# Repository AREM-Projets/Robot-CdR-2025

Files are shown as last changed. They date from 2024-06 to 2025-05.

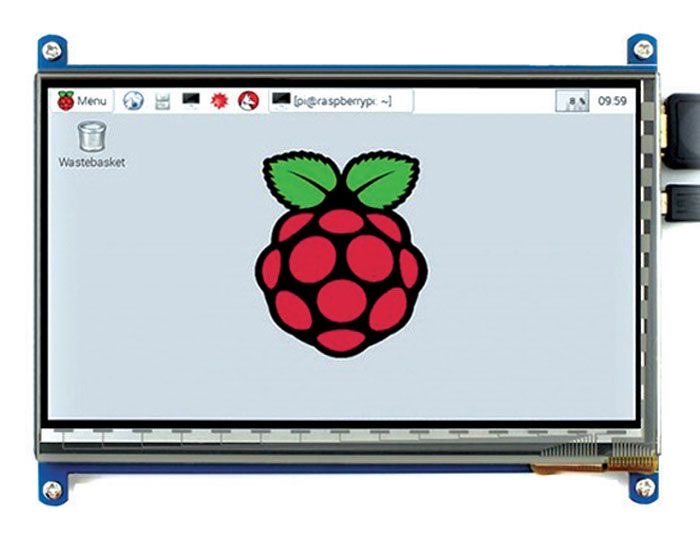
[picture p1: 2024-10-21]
Docs/Architecture ancienne du robot/Images/ecran_tactile.jpg

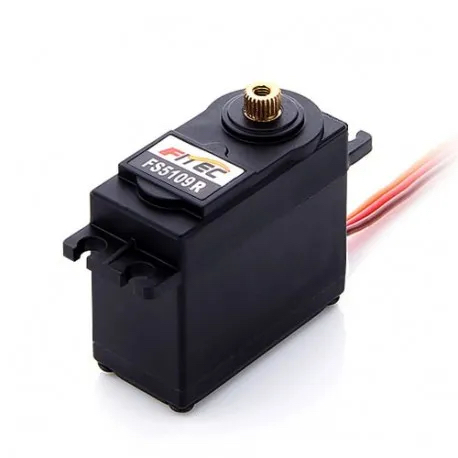
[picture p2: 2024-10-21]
Docs/Architecture ancienne du robot/Images/servo.webp

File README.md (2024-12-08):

# Robot-CdR-2025

Repo contenant l'ensemble des documents liés au robot de la coupe de France de Robotique 2025

## Liens utiles

* [Notion des tâches à réaliser](https://gevorgs.notion.site/2f7c12f6feff4595ba645344655ddd17?v=308f1cf20fb54248941d14f6b965dd2d)
* [Lien vers le règlement](https://www.coupederobotique.fr/accueil/le-concours/reglement-2025/)

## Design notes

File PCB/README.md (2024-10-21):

# PCB utilisés pour le robot de la CdR 2025

* PCB Alimentation
* PCB Shield STM32 Embase

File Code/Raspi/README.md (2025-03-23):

# Robot-CdR-2025

Repo contenant l'ensemble du code du robot de la coupe de France de Robotique 2025.

## TODO

- Faire un script bash qui démarre le main.py du robot, crées la fifo_lidar_to_raspi et démarre le driver_lidar

## LIDAR

>**Compilation du driver lidar**: ``bash driver_lidar_compilation.sh``
>**Démarrage du driver lidar**: ``./driver_lidar --channel --serial /dev/ttyUSB0 460800``

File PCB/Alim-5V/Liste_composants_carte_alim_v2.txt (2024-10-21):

ok	4 connecteurs jack femelle
ok	1 led rouge
ok	1 resistance 1kOhms
ok	1 fusible
ok	8 JST 2 pin femelles
nok	1 Port XT60 femelle (on a les mâles)
ok	3 Bucks

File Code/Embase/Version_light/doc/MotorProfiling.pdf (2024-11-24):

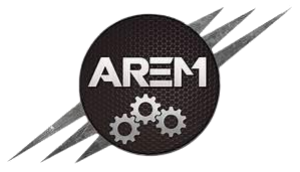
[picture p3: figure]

# [Component Test] Stepper Motor

Date : 08/01/22

Author : Adrien Komaroff-Kourloff

Purpose of the task:

- Principle: Operate the stepper motor that will be used on both robots. Write a brief report on its operation (including the written functions). Find the optimal operating parameters for the motor.
- Objectives: Familiarize yourself with the operation of stepper motors, prepare for their integration into the code.

## Ressources :

To understand the principle of a stepper motor: Stepper Motor Principle (http://ressources.univ-lemans.fr/AccesLibre/UM/Pedago/physique/02/electri/pasapas.html)

For information on micro-stepping: Microstepping Basics (https://www.linearmotiontips.com/microstepping-basics/)

The hardware connections to be made are detailed in the motor shield component test.

## Parameter Optimization

To achieve the best performance with the motors, it is necessary to have a good understanding of the parameters in the BlocMoteurs.h file :

Modify that struct : init for each motor

De L6470_init_t initShield[L6470DAISYCHAINSIZE]

For this purpose, I have adapted the content of this technical document, which is recommended reading: STMicroelectronics Voltage Mode Control Operation and Parameter Optimization. (https://www.st.com/resource/en/application_note/an4144-voltage-mode-control-operation-and-parameter-optimization-stmicroelectronics.pdf)

Please be aware that the library already performs some calculations after filling in L6470_init_t, and the units and quantities in this technical note may not be exactly the same as what needs to be filled in. You should adapt them based on a study of this library and its various functions.

To find the motor parameters, you need to have various parameters available in the motor datasheet and obtain them through measurement.

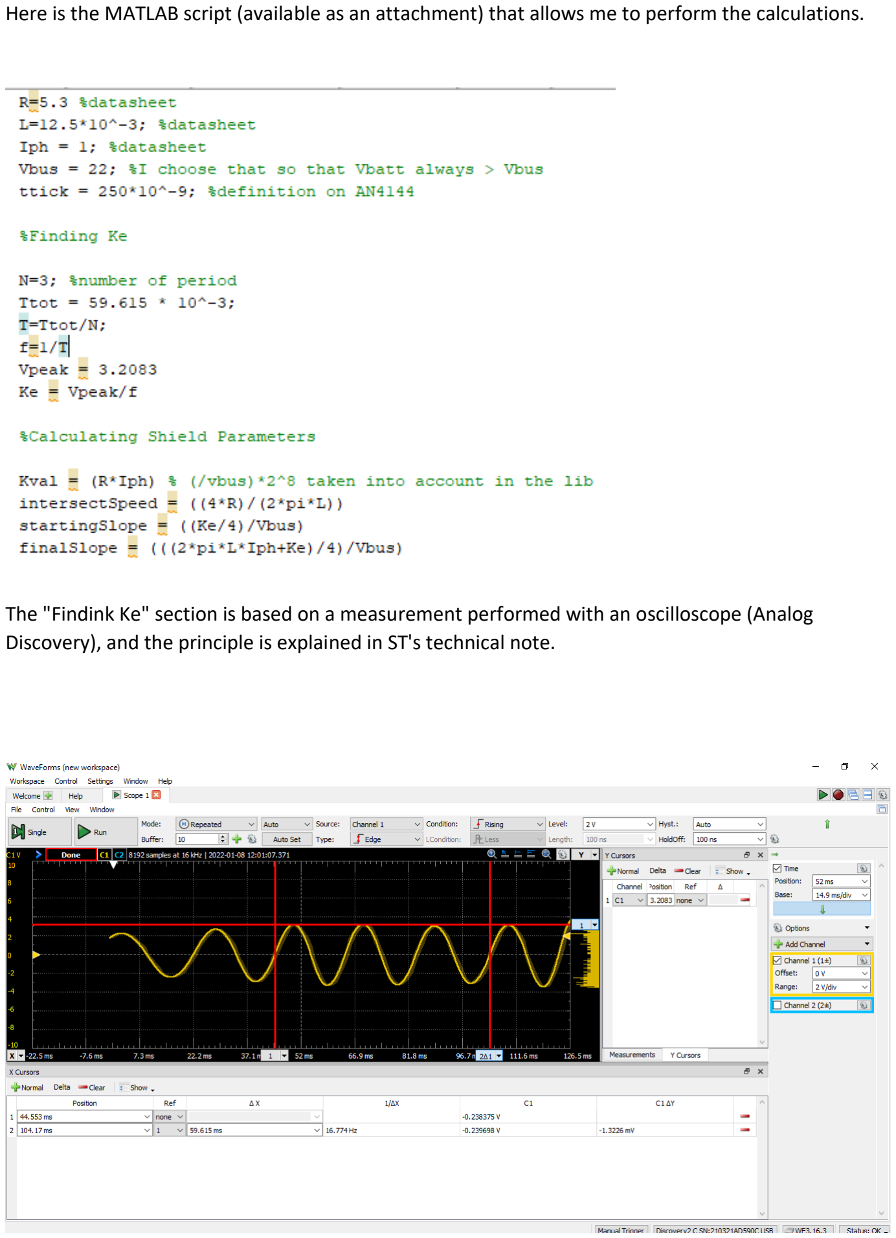
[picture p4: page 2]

Here is the MATLAB script (available as an attachment) that allows me to perform the calculations.

The "Findink Ke" section is based on a measurement performed with an oscilloscope (Analog Discovery), and the principle is explained in ST's technical note.

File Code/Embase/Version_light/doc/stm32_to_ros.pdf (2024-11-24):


01/11/2023

stm32_to_ros Project
Configuration Report

## 1. Description

### 1.1. Project

Project Name | stm32_to_ros
Board Name | NUCLEO-F446RE
Generated with: | STM32CubeMX 6.9.2
Date | 11/01/2023

### 1.2. MCU

MCU Series | STM32F4
MCU Line | STM32F446
MCU name | STM32F446RETx
MCU Package | LQFP64
MCU Pin number | 64

### 1.3. Core(s) information

Core(s) | Arm Cortex-M4

## 2. Pinout Configuration

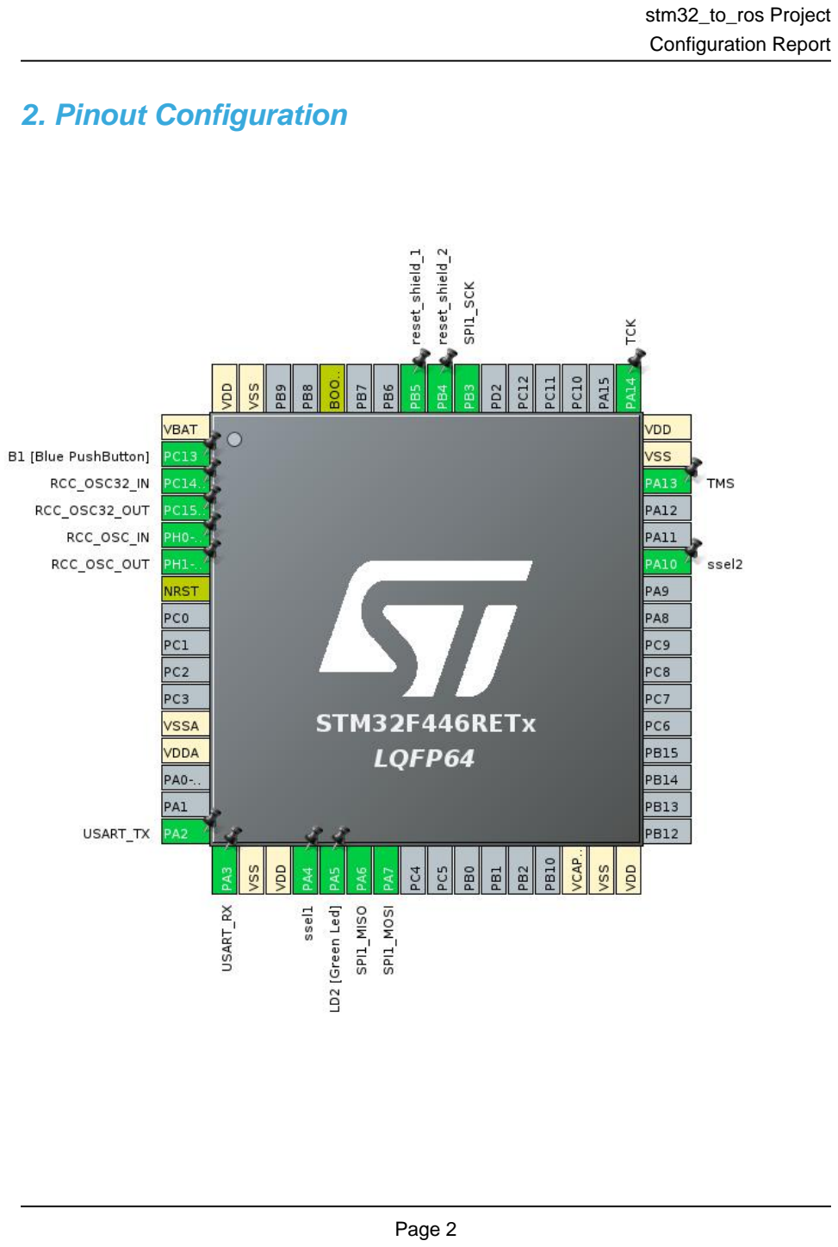
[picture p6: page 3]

## 3. Pins Configuration

Pin Number LQFP64 | Pin Name (function after reset) | Pin Type | Alternate Function(s) | Label
1 | VBAT | Power
2 | PC13 | I/O | GPIO_EXTI13 | B1 [Blue PushButton]
3 | PC14-OSC32_IN | I/O | RCC_OSC32_IN
4 | PC15-OSC32_OUT | I/O | RCC_OSC32_OUT
5 | PH0-OSC_IN | I/O | RCC_OSC_IN
6 | PH1-OSC_OUT | I/O | RCC_OSC_OUT
7 | NRST | Reset
12 | VSSA | Power
13 | VDDA | Power
16 | PA2 | I/O | USART2_TX | USART_TX
17 | PA3 | I/O | USART2_RX | USART_RX
18 | VSS | Power
19 | VDD | Power
20 | PA4 * | I/O | GPIO_Output | ssel1
21 | PA5 * | I/O | GPIO_Output | LD2 [Green Led]
22 | PA6 | I/O | SPI1_MISO
23 | PA7 | I/O | SPI1_MOSI
30 | VCAP_1 | Power
31 | VSS | Power
32 | VDD | Power
43 | PA10 * | I/O | GPIO_Output | ssel2
46 | PA13 | I/O | SYS_JTMS-SWDIO | TMS
47 | VSS | Power
48 | VDD | Power
49 | PA14 | I/O | SYS_JTCK-SWCLK | TCK
55 | PB3 | I/O | SPI1_SCK
56 | PB4 * | I/O | GPIO_Output | reset_shield_2
57 | PB5 * | I/O | GPIO_Output | reset_shield_1
60 | BOOT0 | Boot
63 | VSS | Power
64 | VDD | Power

* The pin is affected with an I/O function

## 4. Clock Tree Configuration

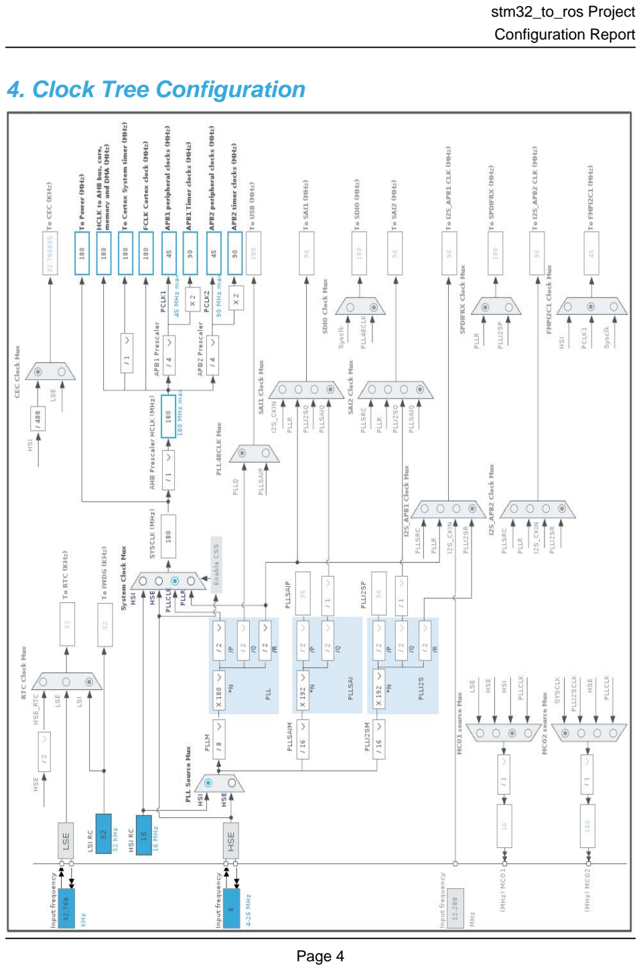
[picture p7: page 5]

## 5. Software Project

### 5.1. Project Settings

Name | Value
Project Name | stm32_to_ros
Project Folder | /home/adrien/STM32CubeIDE/workspace_1.13.2/stm32_to_ros
Toolchain / IDE | STM32CubeIDE
Firmware Package Name and Version | STM32Cube FW_F4 V1.27.1
Application Structure | Advanced
Generate Under Root | Yes
Do not generate the main() | No
Minimum Heap Size | 0x200
Minimum Stack Size | 0x400

### 5.2. Code Generation Settings

Name | Value
STM32Cube MCU packages and embedded software | Copy only the necessary library files
Generate peripheral initialization as a pair of '.c/.h' files | No
Backup previously generated files when re-generating | No
Keep User Code when re-generating | Yes
Delete previously generated files when not re-generated | Yes
Set all free pins as analog (to optimize the power consumption) | No
Enable Full Assert | No

### 5.3. Advanced Settings - Generated Function Calls

Rank | Function Name | Peripheral Instance Name
1 | SystemClock_Config | RCC
2 | MX_GPIO_Init | GPIO
3 | MX_USART2_UART_Init | USART2
4 | MX_TIM2_Init | TIM2
5 | MX_SPI1_Init | SPI1

## 1. Power Consumption Calculator report

### 1.1. Microcontroller Selection

Series | STM32F4
Line | STM32F446
MCU | STM32F446RETx
Datasheet | DS10693_Rev6

### 1.2. Parameter Selection

Temperature | 25
Vdd | 3.3

### 1.3. Battery Selection

Battery | Li-SOCL2(A3400)
Capacity | 3400.0 mAh
Self Discharge | 0.08 %/month
Nominal Voltage | 3.6 V
Max Cont Current | 100.0 mA
Max Pulse Current | 200.0 mA
Cells in series | 1
Cells in parallel | 1

### 1.4. Sequence

Step | Step1 | Step2
Mode | RUN | STOP_UDM (Under Drive)
Vdd | 3.3 | 3.3
Voltage Source | Battery | Battery
Range | Scale1-High | No Scale
Fetch Type | RAM/FLASH/REGON/ART/P REFETCH | n/a
CPU Frequency | 180 MHz | 0 Hz
Clock Configuration | HSE PLL | Regulator_LP Flash-PwrDwn
Clock Source Frequency | 4 MHz | 0 Hz
Peripherals
Additional Cons. | 0 mA | 0 mA
Average Current | 46 mA | 55 µA
Duration | 0.1 ms | 0.9 ms
DMIPS | 225.0 | 0.0
Ta Max | 98.02 | 104.99
Category | In DS Table | In DS Table

### 1.5. Results

Sequence Time | 1 ms | Average Current | 4.65 mA
Battery Life | 1 month | Average DMIPS | 225.0 DMIPS

### 1.6. Chart

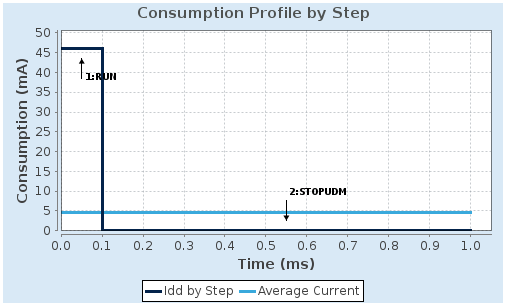
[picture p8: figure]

## 2. Peripherals and Middlewares Configuration

### 2.1. RCC

High Speed Clock (HSE): Crystal/Ceramic Resonator
Low Speed Clock (LSE) : Crystal/Ceramic Resonator
2.1.1. Parameter Settings:

System Parameters:

VDD voltage (V) | 3.3
Instruction Cache | Enabled
Prefetch Buffer | Enabled
Data Cache | Enabled
Flash Latency(WS) | 5 WS (6 CPU cycle)
RCC Parameters:
HSI Calibration Value | 16
TIM Prescaler Selection | Disabled
HSE Startup Timout Value (ms) | 100
LSE Startup Timout Value (ms) | 5000
Power Parameters:
Power Regulator Voltage Scale | Power Regulator Voltage Scale 1
Power Over Drive | Enabled

### 2.2. SPI1

Mode: Full-Duplex Master
2.2.1. Parameter Settings:

Basic Parameters:

Frame Format | Motorola
Data Size | 8 Bits
First Bit | MSB First
Clock Parameters:
Prescaler (for Baud Rate) | 8 *
Baud Rate | 5.625 MBits/s *
Clock Polarity (CPOL) | High *
Clock Phase (CPHA) | 2 Edge *
Advanced Parameters:
CRC Calculation | Disabled
NSS Signal Type | Software

### 2.3. SYS

Debug: Serial Wire
Timebase Source: SysTick

### 2.4. TIM2

Clock Source : Internal Clock
2.4.1. Parameter Settings:

Counter Settings:

Prescaler (PSC - 16 bits value) | 0
Counter Mode | Up
Counter Period (AutoReload Register - 32 bits value ) | 1800000 *
Internal Clock Division (CKD) | No Division
auto-reload preload | Enable *
Trigger Output (TRGO) Parameters:
Master/Slave Mode (MSM bit) | Disable (Trigger input effect not delayed)
Trigger Event Selection | Reset (UG bit from TIMx_EGR)

### 2.5. USART2

Mode: Asynchronous
2.5.1. Parameter Settings:

Basic Parameters:

Baud Rate | 115200
Word Length | 8 Bits (including Parity)
Parity | None
Stop Bits | 1
Advanced Parameters:
Data Direction | Receive and Transmit
Over Sampling | 16 Samples

* User modified value

## 3. System Configuration

### 3.1. GPIO configuration

IP | Pin | Signal | GPIO mode | GPIO pull/up pull down | Max Speed | User Label
RCC | PC14-OSC32_IN | RCC_OSC32_IN | n/a | n/a | n/a
| PC15-OSC32_OU T | RCC_OSC32_O UT | n/a | n/a | n/a
| PH0-OSC_IN | RCC_OSC_IN | n/a | n/a | n/a
| PH1-OSC_OUT | RCC_OSC_OUT | n/a | n/a | n/a
SPI1 | PA6 | SPI1_MISO | Alternate Function Push Pull | No pull-up and no pull-down | Very High *
| PA7 | SPI1_MOSI | Alternate Function Push Pull | No pull-up and no pull-down | Very High *
| PB3 | SPI1_SCK | Alternate Function Push Pull | No pull-up and no pull-down | Very High *
SYS | PA13 | SYS_JTMS-SWDIO | n/a | n/a | n/a | TMS
| PA14 | SYS_JTCK-SWCLK | n/a | n/a | n/a | TCK
USART2 | PA2 | USART2_TX | Alternate Function Push Pull | No pull-up and no pull-down | Very High * | USART_TX
| PA3 | USART2_RX | Alternate Function Push Pull | No pull-up and no pull-down | Very High * | USART_RX
GPIO | PC13 | GPIO_EXTI13 | External Interrupt Mode with Falling edge trigger detection | No pull-up and no pull-down | n/a | B1 [Blue PushButton]
| PA4 | GPIO_Output | Output Push Pull | No pull-up and no pull-down | Low | ssel1
| PA5 | GPIO_Output | Output Push Pull | No pull-up and no pull-down | Low | LD2 [Green Led]
| PA10 | GPIO_Output | Output Push Pull | No pull-up and no pull-down | Low | ssel2
| PB4 | GPIO_Output | Output Push Pull | No pull-up and no pull-down | Low | reset_shield_2
| PB5 | GPIO_Output | Output Push Pull | No pull-up and no pull-down | Low | reset_shield_1

### 3.2. DMA configuration

nothing configured in DMA service

### 3.3. NVIC configuration

3.3.1. NVIC
Interrupt Table | Enable | Preenmption Priority | SubPriority
Non maskable interrupt | true | 0 | 0
Hard fault interrupt | true | 0 | 0
Memory management fault | true | 0 | 0
Pre-fetch fault, memory access fault | true | 0 | 0
Undefined instruction or illegal state | true | 0 | 0
System service call via SWI instruction | true | 0 | 0
Debug monitor | true | 0 | 0
Pendable request for system service | true | 0 | 0
System tick timer | true | 0 | 0
TIM2 global interrupt | true | 0 | 2
USART2 global interrupt | true | 0 | 0
PVD interrupt through EXTI line 16 | unused
Flash global interrupt | unused
RCC global interrupt | unused
SPI1 global interrupt | unused
EXTI line[15:10] interrupts | unused
FPU global interrupt | unused
3.3.2. NVIC Code generation
Enabled interrupt Table | Select for init sequence ordering | Generate IRQ handler | Call HAL handler
Non maskable interrupt | false | true | false
Hard fault interrupt | false | true | false
Memory management fault | false | true | false
Pre-fetch fault, memory access fault | false | true | false
Undefined instruction or illegal state | false | true | false
System service call via SWI instruction | false | true | false
Debug monitor | false | true | false
Pendable request for system service | false | true | false
System tick timer | false | true | true
TIM2 global interrupt | false | true | true
USART2 global interrupt | false | true | true

* User modified value

## 4. System Views

4.1. Category view
4.1.1. Current

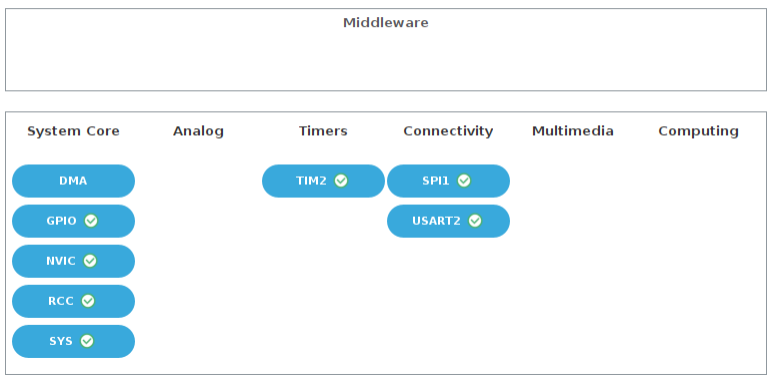
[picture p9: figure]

## 5. Docs & Resources

Type | Link
BSDL files | https://www.st.com/resource/en/bsdl_model/stm32f446_bsdl.zip
IBIS models | https://www.st.com/resource/en/ibis_model/stm32f446_ibis.zip
System View Description | https://www.st.com/resource/en/svd/stm32f4_svd.zip
Presentations | https://www.st.com/resource/en/product_presentation/stm32-stm8_embedded_software_solutions.pdf
Presentations | https://www.st.com/resource/en/product_presentation/stm32_eval-tools_portfolio.pdf
Presentations | https://www.st.com/resource/en/product_presentation/stm32_stm8_functi onal-safety-packages.pdf
Presentations | https://www.st.com/resource/en/product_presentation/stm32-stm8_software_development_tools.pdf
Brochures | https://www.st.com/resource/en/brochure/products-and-solutions-for-plcs-and-smart-i-os.pdf
Flyers | https://www.st.com/resource/en/flyer/flstm32nucleo.pdf
Flyers | https://www.st.com/resource/en/flyer/flstmcsuite.pdf
Flyers | https://www.st.com/resource/en/flyer/flstm32trust.pdf
Product Certifications | https://www.st.com/resource/en/certification_document/stm32_authentication_can.pdf
Application Notes | https://www.st.com/resource/en/application_note/an1181-electrostatic-discharge-sensitivity-measurement-stmicroelectronics.pdf
Application Notes | https://www.st.com/resource/en/application_note/an1709-emc-design-guide-for-stm8-stm32-and-legacy-mcus-stmicroelectronics.pdf
Application Notes | https://www.st.com/resource/en/application_note/an2606-stm32-microcontroller-system-memory-boot-mode-stmicroelectronics.pdf
Application Notes | https://www.st.com/resource/en/application_note/an2639-soldering-recommendations-and-package-information-for-leadfree-ecopack-mcus-and-mpus-stmicroelectronics.pdf
Application Notes | https://www.st.com/resource/en/application_note/an2834-how-to-get-the-

| best-adc-accuracy-in-stm32-microcontrollers-stmicroelectronics.pdf
Application Notes | https://www.st.com/resource/en/application_note/an2867-oscillator-design-guide-for-stm8afals-stm32-mcus-and-mpus-stmicroelectronics.pdf
Application Notes | https://www.st.com/resource/en/application_note/an2945-stm8s-and-stm32-mcus-a-consistent-832bit-product-line-for-painless-migration-stmicroelectronics.pdf
Application Notes | https://www.st.com/resource/en/application_note/an3070-managing-the-driver-enable-signal-for-rs485-and-iolink-communications-with-the-stm32s-usart-stmicroelectronics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
Application Notes | https://www.st.com/resource/en/application_note/an3126-audio-and-waveform-generation-using-the-dac-in-stm32-products-stmicroelectronics.pdf
Application Notes | https://www.st.com/resource/en/application_note/an3154-can-protocol-used-in-the-stm32-bootloader-stmicroelectronics.pdf
Application Notes | https://www.st.com/resource/en/application_note/an3155-usart-protocol-used-in-the-stm32-bootloader-stmicroelectronics.pdf
Application Notes | https://www.st.com/resource/en/application_note/an3156-usb-dfu-protocol-used-in-the-stm32-bootloader-stmicroelectronics.pdf
Application Notes | https://www.st.com/resource/en/application_note/an3364-migration-and-compatibility-guidelines-for-stm32-microcontroller-applications-stmicroelectronics.pdf
Application Notes | https://www.st.com/resource/en/application_note/an3997-audio-playback-and-recording-using-the-stm32f4discovery-stmicroelectronics.pdf
Application Notes | https://www.st.com/resource/en/application_note/an3998-pdm-audio-software-decoding-on-stm32-microcontrollers-stmicroelectronics.pdf
Application Notes | https://www.st.com/resource/en/application_note/an4013-stm32-crossseries-timer-overview-stmicroelectronics.pdf
Application Notes | https://www.st.com/resource/en/application_note/an4031-using-the-stm32f2-stm32f4-and-stm32f7-series-dma-controller-stmicroelectronics.pdf
Application Notes | https://www.st.com/resource/en/application_note/an4221-i2c-protocol-used-in-the-stm32-bootloader-stmicroelectronics.pdf
Application Notes | https://www.st.com/resource/en/application_note/an4229-how-to-

| implement-a-vocoder-solution-using-stm32-microcontrollers-stmicroelectronics.pdf
Application Notes | https://www.st.com/resource/en/application_note/an4277-using-stm32-device-pwm-shutdown-features-for-motor-control-and-digital-power-conversion-stmicroelectronics.pdf
Application Notes | https://www.st.com/resource/en/application_note/an4286-spi-protocol-used-in-the-stm32-bootloader-stmicroelectronics.pdf
Application Notes | https://www.st.com/resource/en/application_note/an4488-getting-started-with-stm32f4xxxx-mcu-hardware-development-stmicroelectronics.pdf
Application Notes | https://www.st.com/resource/en/application_note/an4566-extending-the-dac-performance-of-stm32-microcontrollers-stmicroelectronics.pdf
Application Notes | https://www.st.com/resource/en/application_note/an4640-peripherals-interconnections-on-stm32f4057xx-stm32f4157xx-stm32f42xxx-stm32f43xxx-stm32f446xx-and-stm32f469479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
Application Notes | https://www.st.com/resource/en/application_note/an4655-virtually-increasing-the-number-of-serial-communication-peripherals-in-stm32-applications-stmicroelectronics.p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
Application Notes | https://www.st.com/resource/en/application_note/an4658-migration-of-applications-from-stm32f429439-lines-to-stm32f446-line-stmicroelectronics.pdf
Application Notes | https://www.st.com/resource/en/application_note/an4739-stm32cube-firmware-examples-for-stm32f4-series-stmicroelectronics.pdf
Application Notes | https://www.st.com/resource/en/application_note/an4750-handling-of-soft-errors-in-stm32-applications-stmicroelectronics.pdf
Application Notes | https://www.st.com/resource/en/application_note/an4759-using-the-hardware-realtime-clock-rtc-and-the-tamper-management-unit-tamp-with-stm32-microcontrollers-stmicroe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
Application Notes | https://www.st.com/resource/en/application_note/an4776-generalpurpose-timer-cookbook-for-stm32-microcontrollers-stmicroelectronics.pdf
Application Notes | https://www.st.com/resource/en/application_note/an4803-highspeed-si-simulations-using-ibis-and-boardlevel-simulations-using-hyperlynx-si-on-stm32-mcus-and-mpus-stmic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
Application Notes | https://www.st.com/resource/en/application_note/an4850-stm32-mcus-

| spreadspectrum-clock-generation-principles-properties-and-implementation-stmicroelectronics.pdf
Application Notes | https://www.st.com/resource/en/application_note/an4908-stm32-usart-automatic-baud-rate-detection-stmicroelectronics.pdf
Application Notes | https://www.st.com/resource/en/application_note/an4989-stm32-microcontroller-debug-toolbox-stmicroelectronics.pdf
Application Notes | https://www.st.com/resource/en/application_note/an4995-using-an-electromyogram-technique-to-detect-muscle-activity-stmicroelectronics.pdf
Application Notes | https://www.st.com/resource/en/application_note/an5020-digital-camera-interface-dcmi-on-stm32-mcus-stmicroelectronics.pdf
Application Notes | https://www.st.com/resource/en/application_note/an5027-interfacing-pdm-digital-microphones-using-stm32-mcus-and-mpus-stmicroelectronics.pdf
Application Notes | https://www.st.com/resource/en/application_note/an5036-thermal-management-guidelines-for-stm32-applications-stmicroelectronics.pdf
Application Notes | https://www.st.com/resource/en/application_note/an5073-receiving-spdif-audio-stream-with-the-stm32f4f7h7-series-stmicroelectronics.pdf
Application Notes | https://www.st.com/resource/en/application_note/an5225-usb-typec-power-delivery-using-stm32-mcus-and-mpus-stmicroelectronics.pdf
Application Notes | https://www.st.com/resource/en/application_note/an5543-enhanced-methods-to-handle-spi-communication-on-stm32-devices-stmicroelectronics.pdf
Application Notes | https://www.st.com/resource/en/application_note/an4760-quadspi-interface-on-stm32-microcontrollers-and-microprocessors--stmicroelectronics.pdf
Application Notes | https://www.st.com/resource/en/application_note/an4899-stm32-microcontroller-gpio-hardware-settings-and-lowpower-consumption-stmicroelectronics.pdf
Application Notes | https://www.st.com/resource/en/application_note/an5612-esd-protection-of-stm32-mcus-and-mpus-stmicroelectronics.pdf
Application Notes | https://www.st.com/resource/en/application_note/an5156-introduction-to-stm32-microcontrollers-security-stmicroelectronics.pdf
Application Notes | https://www.st.com/resource/en/application_note/an4838-introduction-to-

| memory-protection-unit-management-on-stm32-mcus-stmicroelectronics.pdf
Application Notes | https://www.st.com/resource/en/application_note/an4230-random-number-generation-validation-using-nist-statistical-test-suite-for-stm32-microcontrollers-stmicroelectr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
Application Notes | https://www.st.com/resource/en/application_note/an4879-introduction-to-usb-hardware-and-pcb-guidelines-using-stm32-mcus-stmicroelectronics.pdf
Application Notes for related Tools & Software | https://www.st.com/resource/en/application_note/an1202_freertos_guide-freertos-guide-stmicroelectronics.pdf
Application Notes for related Tools & Software | https://www.st.com/resource/en/application_note/an1602_semihosting_in_truestudio-how-to-do-semihosting-in-truestudio-stmicroelectronics.pdf
Application Notes for related Tools & Software | https://www.st.com/resource/en/application_note/an1801_stm32cubeprogrammer_in_truestudio-installing-stm32cubeprogrammer-in-truestudio-stmicroelectronics.pdf
Application Notes for related Tools & Software | https://www.st.com/resource/en/application_note/atollic_editing_keyboard_shortcuts-atollic-editing-keyboard-shortcuts-stmicroelectronics.pdf
Application Notes for related Tools & Software | https://www.st.com/resource/en/application_note/iar_to_atollic_truestudio_migration_guide-truestudio-for-arm-migration-guide-iar-embedded-workbench-to-truestudio-stm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
Application Notes for related Tools & Software | https://www.st.com/resource/en/application_note/stm32cubemx_installation_in_truestudio-stm32cubemx-installation-in-truestudio-stmicroelectronics.pdf
Application Notes for related Tools & Software | https://www.st.com/resource/en/application_note/an2656-stm32f10xxx-lcd-glass-driver-firmware-stmicroelectronics.pdf
Application Notes for related Tools & Software | https://www.st.com/resource/en/application_note/an2790-tft-lcd-interfacing-with-the-highdensity-stm32f10xxx-fsmc-stmicroelectronics.pdf

Application Notes
for related Tools

https://www.st.com/resource/en/application_note/an3078-stm32-inapplication-programming-over-the-ic-bus-stmicroelectronics.pdf

& Software
Application Notes for related Tools & Software | https://www.st.com/resource/en/application_note/an3116-stm32s-adc-modes-and-their-applications-stmicroelectronics.pdf
Application Notes for related Tools & Software | https://www.st.com/resource/en/application_note/an3174-implementing-receivers-for-infrared-remote-control-protocols-using-stm32f10xxx-microcontrollers-stmicroelectro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
Application Notes for related Tools & Software | https://www.st.com/resource/en/application_note/an3241-qvga-tftlcd-direct-drive-using-the-stm32f10xx-fsmc-peripheral-stmicroelectronics.pdf
Application Notes for related Tools & Software | https://www.st.com/resource/en/application_note/an3307-guidelines-for-obtaining-iec-60335-class-b-certification-for-any-stm32-application-stmicroelectronics.pdf
Application Notes for related Tools & Software | https://www.st.com/resource/en/application_note/an3364-migration-and-compatibility-guidelines-for-stm32-microcontroller-applications-stmicroelectronics.pdf
Application Notes for related Tools & Software | https://www.st.com/resource/en/application_note/an3965-stm32f40xstm32f41x-inapplication-programming-using-the-usart-stmicroelectronics.pdf
Application Notes for related Tools & Software | https://www.st.com/resource/en/application_note/an3969-eeprom-emulation-in-stm32f40xstm32f41x-microcontrollers-stmicroelectronics.pdf
Application Notes for related Tools & Software | https://www.st.com/resource/en/application_note/an3990-upgrading-stm32f4discovery-board-firmware-using-a-usb-key-stmicroelectronics.pdf
Application Notes for related Tools & Software | https://www.st.com/resource/en/application_note/an3997-audio-playback-and-recording-using-the-stm32f4discovery-stmicroelectronics.pdf
Application Notes for related Tools & Software | https://www.st.com/resource/en/application_note/an3998-pdm-audio-software-decoding-on-stm32-microcontrollers-stmicroelectronics.pdf
Application Notes for related Tools & Software | https://www.st.com/resource/en/application_note/an4044-floating-point-unit-demonstration-on-stm32-microcontrollers-stmicroelectronics.pdf

Application Notes for related Tools & Software | https://www.st.com/resource/en/application_note/an4323-getting-started-with-stemwin-library-stmicroelectronics.pdf
Application Notes for related Tools & Software | https://www.st.com/resource/en/application_note/an4365-using-stm32f4-mcu-power-modes-with-best-dynamic-efficiency-stmicroelectronics.pdf
Application Notes for related Tools & Software | https://www.st.com/resource/en/application_note/an4435-guidelines-for-obtaining-ulcsaiec-607301603351-class-b-certification-in-any-stm32-application-stmicroelectroni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
Application Notes for related Tools & Software | https://www.st.com/resource/en/application_note/an4457-implementing-an-emulated-uart-on-stm32f4-microcontrollers-stmicroelectronics.pdf
Application Notes for related Tools & Software | https://www.st.com/resource/en/application_note/an4499-stm32--nrf51822-bluetooth-low-energy-system-solution-stmicroelectronics.pdf
Application Notes for related Tools & Software | https://www.st.com/resource/en/application_note/an4657-stm32-inapplication-programming-iap-using-the-usart-stmicroelectronics.pdf
Application Notes for related Tools & Software | https://www.st.com/resource/en/application_note/an4666-parallel-synchronous-transmission-using-gpio-and-dma-stmicroelectronics.pdf
Application Notes for related Tools & Software | https://www.st.com/resource/en/application_note/an4678-full-duplex-spi-emulation-for-stm32f4-microcontrollers-stmicroelectronics.pdf
Application Notes for related Tools & Software | https://www.st.com/resource/en/application_note/an4701-proprietary-code-readout-protection-on-microcontrollers-of-the-stm32f4-series-stmicroelectronics.pdf
Application Notes for related Tools & Software | https://www.st.com/resource/en/application_note/an4739-stm32cube-firmware-examples-for-stm32f4-series-stmicroelectronics.pdf
Application Notes for related Tools & Software | https://www.st.com/resource/en/application_note/an4758-proprietary-code-readout-protection-on-stm32l4-stm32l4-stm32g4-and-stm32wb-series-mcus-stmicroelectronics.pdf
Application Notes | https://www.st.com/resource/en/application_note/an4759-using-the-

for related Tools & Software | hardware-realtime-clock-rtc-and-the-tamper-management-unit-tamp-with-stm32-microcontrollers-stmicroelectronics.pdf
Application Notes for related Tools & Software | https://www.st.com/resource/en/application_note/an4841-digital-signal-processing-for-stm32-microcontrollers-using-cmsis-stmicroelectronics.pdf
Application Notes for related Tools & Software | https://www.st.com/resource/en/application_note/an4852-programming-an-external-flash-memory-using-the-uart-bootloader-builtin-stm32-microcontrollers-stmicroelectroni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
Application Notes for related Tools & Software | https://www.st.com/resource/en/application_note/an4968-proprietary-code-read-out-protection-pcrop-on-stm32f72xxx-and-stm32f73xxx-microcontrollers-stmicroelectronics.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
Application Notes for related Tools & Software | https://www.st.com/resource/en/application_note/an5054-secure-programming-using-stm32cubeprogrammer-stmicroelectronics.pdf
Application Notes for related Tools & Software | https://www.st.com/resource/en/application_note/an5056-integration-guide-for-the-xcubesbsfu-stm32cube-expansion-package-stmicroelectronics.pdf
Application Notes for related Tools & Software | https://www.st.com/resource/en/application_note/an5360-getting-started-with-projects-based-on-the-stm32mp1-series-in-stm32cubeide-stmicroelectronics.pdf
Application Notes for related Tools & Software | https://www.st.com/resource/en/application_note/an5361-getting-started-with-projects-based-on-dualcore-stm32h7-microcontrollers-in-stm32cubeide-stmicroelectronics.pd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
Application Notes for related Tools & Software | https://www.st.com/resource/en/application_note/an5394-getting-started-with-projects-based-on-the-stm32l5-series-in-stm32cubeide-stmicroelectronics.pdf
Application Notes for related Tools & Software | https://www.st.com/resource/en/application_note/an5418-how-to-build-a-simple-usbpd-sink-application-with-stm32cubemx-stmicroelectronics.pdf
Application Notes for related Tools & Software | https://www.st.com/resource/en/application_note/an5426-migrating-graphics-middleware-projects-from-stm32cubemx-540-to-stm32cubemx-550-stmicroelectronics.pdf

Application Notes
for related Tools

https://www.st.com/resource/en/application_note/an5464-position-controlof-a-threephase-permanent-magnet-motor-using-xcubemcsdk-or-

& Software | xcubemcsdkful-stmicroelectronics.pdf
Application Notes for related Tools & Software | https://www.st.com/resource/en/application_note/an5564-getting-started-with-projects-based-on-dualcore-stm32wl-microcontrollers-in-stm32cubeide-stmicroelectronics.pd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
Application Notes for related Tools & Software | https://www.st.com/resource/en/application_note/an5698-adapting-the-xcubestl-functional-safety-package-for-stm32-iec-61508-compliant-to-other-safety-standards-stmicr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
Application Notes for related Tools & Software | https://www.st.com/resource/en/application_note/an5731-stm32cubemx-and-stm32cubeide-threadsafe-solution-stmicroelectronics.pdf
Application Notes for related Tools & Software | https://www.st.com/resource/en/application_note/an4502-stm32-smbuspmbus-expansion-package-for-stm32cube-stmicroelectronics.pdf
Errata Sheets | https://www.st.com/resource/en/errata_sheet/es0298-stm32f446xcxe-device-limitations-stmicroelectronics.pdf
Datasheet | https://www.st.com/resource/en/datasheet/dm00141306.pdf
Programming Manuals | https://www.st.com/resource/en/programming_manual/pm0214-stm32-cortexm4-mcus-and-mpus-programming-manual-stmicroelectronics.pdf
Reference Manuals | https://www.st.com/resource/en/reference_manual/rm0390-stm32f446xx-advanced-armbased-32bit-mcus-stmicroelectronics.pdf
Technical Notes & Articles | https://www.st.com/resource/en/technical_note/tn0516-overview-of-the-stm32f0xf100xxf103xx-and-stm32f2xxf30xf4xx-mcus-pmsm-singledual-foc-sdk-v40-stmicroelectronics.p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
Technical Notes & Articles | https://www.st.com/resource/en/technical_note/tn1163-description-of-wlcsp-for-microcontrollers-and-recommendations-for-its-use-stmicroelectronics.pdf
Technical Notes & Articles | https://www.st.com/resource/en/technical_note/tn1204-tape-and-reel-shipping-media-for-stm32-microcontrollers-in-bga-packages-stmicroelectronics.pdf
Technical Notes & Articles | https://www.st.com/resource/en/technical_note/tn1205-tape-and-reel-shipping-media-for-stm8-and-stm32-microcontrollers-in-fpn-packages-stmicroelectronics.pdf
Technical Notes | https://www.st.com/resource/en/technical_note/tn1206-tape-and-reel-

& Articles | shipping-media-for-stm8-and-stm32-microcontrollers-in-qfp-packages-stmicroelectronics.pdf
Technical Notes & Articles | https://www.st.com/resource/en/technical_note/tn1207-tape-and-reel-shipping-media-for-stm8-and-stm32-microcontrollers-in-so-packages-stmicroelectronics.pdf
Technical Notes & Articles | https://www.st.com/resource/en/technical_note/tn1208-tape-and-reel-shipping-media-for-stm8-and-stm32-microcontrollers-in-tssop-and-ssop-packages-stmicroelectronics.p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
Technical Notes & Articles | https://www.st.com/resource/en/technical_note/tn1433-reference-device-marking-schematics-for-stm32-microcontrollers-and-microprocessors-stmicroelectronics.pdf

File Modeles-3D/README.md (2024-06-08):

# Modèles 3D utilisés pour le robot de la CdR 2025

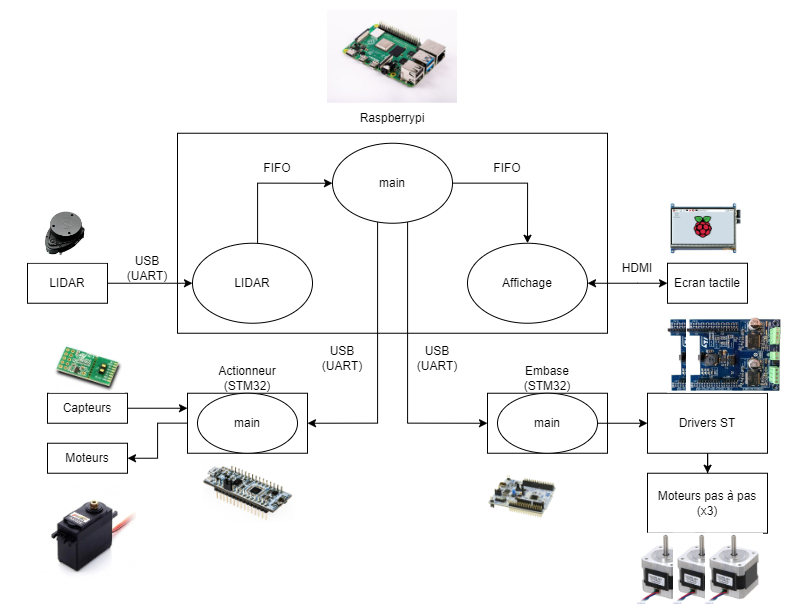
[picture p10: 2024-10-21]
Docs/Architecture ancienne du robot/Rendus/Architecture_hardware&logicielle.png

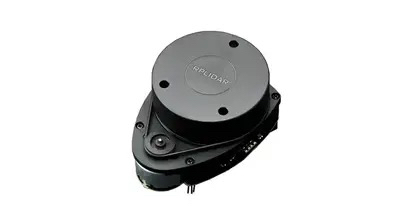
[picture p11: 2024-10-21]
Docs/Architecture ancienne du robot/Images/LIDAR.webp

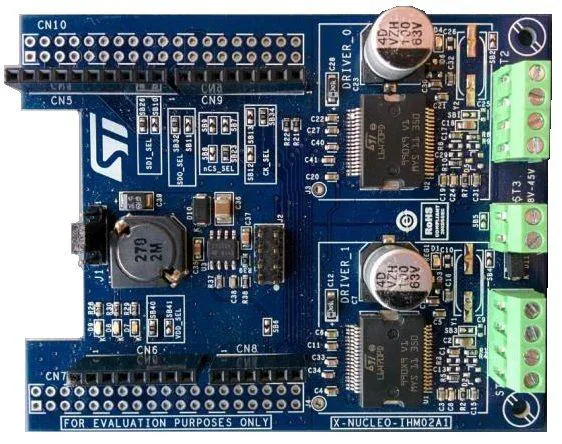
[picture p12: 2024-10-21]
Docs/Architecture ancienne du robot/Images/shield_stepper.webp

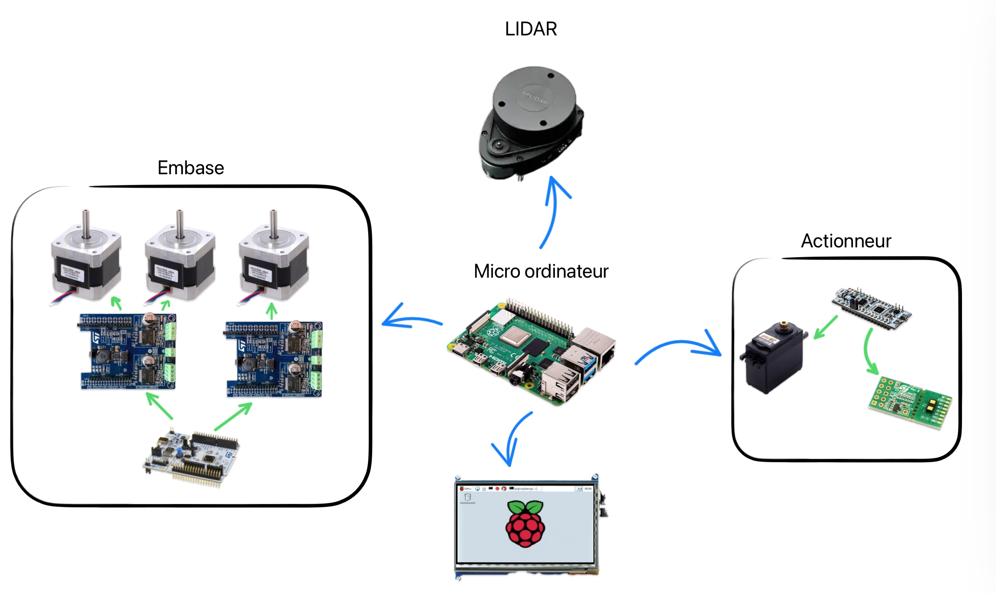
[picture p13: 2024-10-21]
Docs/Architecture ancienne du robot/Rendus/Architecture_simplifie.png

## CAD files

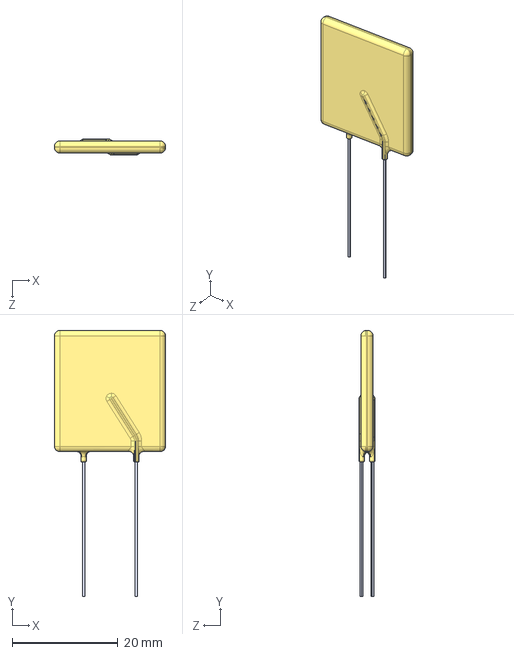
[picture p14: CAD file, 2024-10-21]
PCB/Alim-5V/RKEF400--3DModel-STEP-418109.STEP
21.0 x 50.3 x 3.00 mm

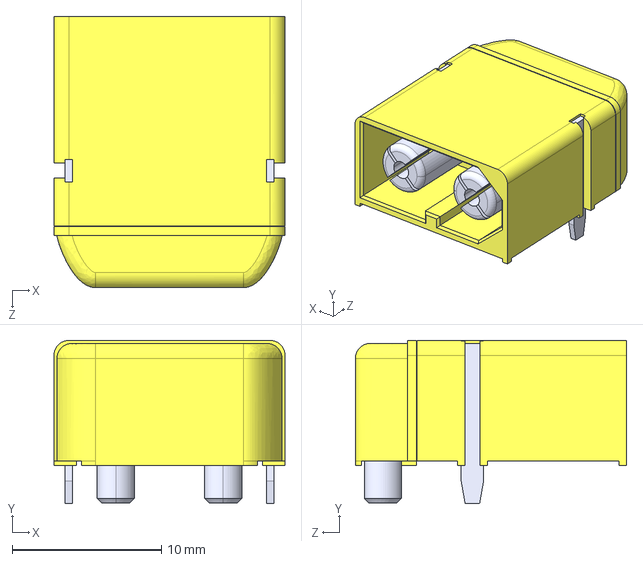
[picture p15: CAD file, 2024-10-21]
PCB/Alim-5V/XT60PW-M.step
15.5 x 11.0 x 18.2 mm

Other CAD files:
Modeles-3D/BAU.ipt
Modeles-3D/Ensemble1.iam
Modeles-3D/actionneur_Support2.ipt
Modeles-3D/actionneur_doigt.ipt
Modeles-3D/actionneur_elevateur/Ensemble1.iam
Modeles-3D/actionneur_elevateur/OldVersions/Ensemble1.0001.iam
Modeles-3D/actionneur_elevateur/OldVersions/rail_principal.0001.ipt
Modeles-3D/actionneur_elevateur/barre_horizontale_support_pinces.ipt
Modeles-3D/actionneur_elevateur/corps_pince_aimant.ipt
Modeles-3D/actionneur_elevateur/rail_principal.ipt
Modeles-3D/actionneur_elevateur/support_aimant_pince.ipt
Modeles-3D/arbre_d_attache (1).ipt
Modeles-3D/base_balises_plateau.ipt
Modeles-3D/batt.ipt
Modeles-3D/couvercle_3roues2.ipt
Modeles-3D/embase_tricorps_1.0.ipt
Modeles-3D/moteur_pasApas.ipt
Modeles-3D/mur_extension_2.ipt
Modeles-3D/roue.ipt
Modeles-3D/roue_actionneur.ipt
Modeles-3D/servomoteur.ipt
Modeles-3D/support banderole.ipt
Modeles-3D/support batterie.ipt

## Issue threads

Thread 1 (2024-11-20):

Filtrer les valeurs du LIDAR

MrBrownFR, 2024-11-20:
# Filtrer les valeurs du LIDAR

## Description

Il faudrait être capable de filtrer les valeurs du LIDAR en fonction de notre position supposée, c'est-à-dire éliminer les valeurs dont on est sûrs qu'elles sont en-dehors de l'arène. Pour ça, il faudrait laisser une marge de manoeuvre d'environ 10 cm autour du rectangle de l'arène (pour garder les piliers).

## Dépendances sur d'autres missions

Aucune

Disperseur, 2024-11-28:
En vrai tu peux juste agrandir le rectangle limite dans la longueur pour avoir les balises. Le soucis est que potentiellement les arbitres seront proches du plateau donc 10cm sur les côtés ça me paraît beaucoup.

Disperseur, 2024-11-28:
Filtrer les valeurs comprends aussi reconnaître des ensembles de points comme des objets .

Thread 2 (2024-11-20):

Déterminer des valeurs stables pour établir la position

MrBrownFR, 2024-11-20:
# Déterminer des valeurs stables pour établir la position

## Description

Il faudrait être capable de déterminer des valeurs stables pour déterminer la position du robot. J'entends par là qu'il faut être capable de déterminer si la donnée qu'on a correspond aux balises ou au robot adverse.

Pour moi, il faudrait maintenir une liste pondérée des potentielles positions du LIDAR. Voici ce que j'ai imaginé avec ça :
- On récupère les valeurs du LIDAR
- On les compare aux précédentes :
  - Si on en a pas, on les stockes avec un poids de 1 (ou autre si on veut travailler avec des entiers)
  - Si on en a :
    - Si la base a bougé de plus d'une certaine quantité (marge d'erreur du LIDAR) on décroît son poids
    - Sinon, on augmente son poids

La difficulté de cet exercice réside dans le fait que la comparaison doit aller extrêmement vite, et donc la structure de données pour la pondération doit supporter deux opérations en une complexité plus faible que O(n) (ou O(n²) selon nos attentes) :
1. Un accès à chacune des balises avec son poids dans l'ordre des angles (O(1) dans un tableau)
2. Un accès aux balises avec les meilleures pondérations pour par la suite déterminer une position absolue dans l'arène

On peut peut-être utiliser un tas, avec le désavantage d'avoir un accès aux balises ordonné en O(log n), mais avec l'avantage d'avoir presque toutes les autres opérations aussi en O(log n).

## Dépendances

- Filtrer les valeurs #1

Disperseur, 2024-11-28:
L'idéal serait de ne parcourir qu'une seule fois les valeurs lues par le Lidar.
Dans un premier temps faire l'algo pour le tester , après on aura le temps d'optimiser. La pi4 est rapide

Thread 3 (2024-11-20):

Etablir une position indépendante de la rotation des roues

MrBrownFR, 2024-11-20:
# Etablir une position indépendante de la rotation des roues

## Description

Il faut être capable de déterminer notre position sur l'arène indépendamment de la rotation des roues. C'est-à-dire que même si on rencontre un obstacle qu'on a pas vu au LIDAR, ou même que le robot adverse nous pousse, on doit être capable de dire que l'on a pas bougé.

Pour ça, un peu de trigo avec un ensemble de balises sûres devrait faire le travail.

## Dépendances

- Obtenir une base stable #2
- Filtrer les valeurs #1

Disperseur, 2024-11-28:
Balises finies et dispo en version 1

Disperseur, 2024-11-28:
Si le robot nous touche et qu'on est à l'arrêt c'est fin du match et on gagne.

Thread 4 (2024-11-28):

Éviter le robot adverse et les obstacles

Disperseur, 2024-11-28:
Avant même le système de positionnement il faut un système d'arrêt si il y a obstacle devant le LIDAR. C'est impératif pour *homologuer*.

Point de potentielle difficulté : filtrer les artefacts vus par le LIDAR pour éviter les arrêts intempestifs (notamment quand il y a une caméra de télévision.).
Idée (utile aussi pour le système de positionnement): faire une fonction qui permet de "reconnaître" un objet via l'ensemble des points mesurés par le LIDAR sur cet objet.

Ce qui avait été fait : 10 points consécutifs espacés de moins de 2 degrés = obstacle. (utilisation d'un compteur incrémenté si point à moins de 2deg d'angle du précédent, décrémenté sinon. Si compteur > seuil (10 par ex) alors arrêt du robot.

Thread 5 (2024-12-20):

Navigation

Disperseur, 2024-12-20:
Un élément important est la navigation. La hiérarchie avec les autres issues est la suivante:
1. Evitement d'obstacle (sa plus simple expression: arrêt si obstacle)
2. Navigation (pouvoir demander d'atteindre une position et y aller)
3. Se positionner avec les balises (lié avec la proposition du dessus)

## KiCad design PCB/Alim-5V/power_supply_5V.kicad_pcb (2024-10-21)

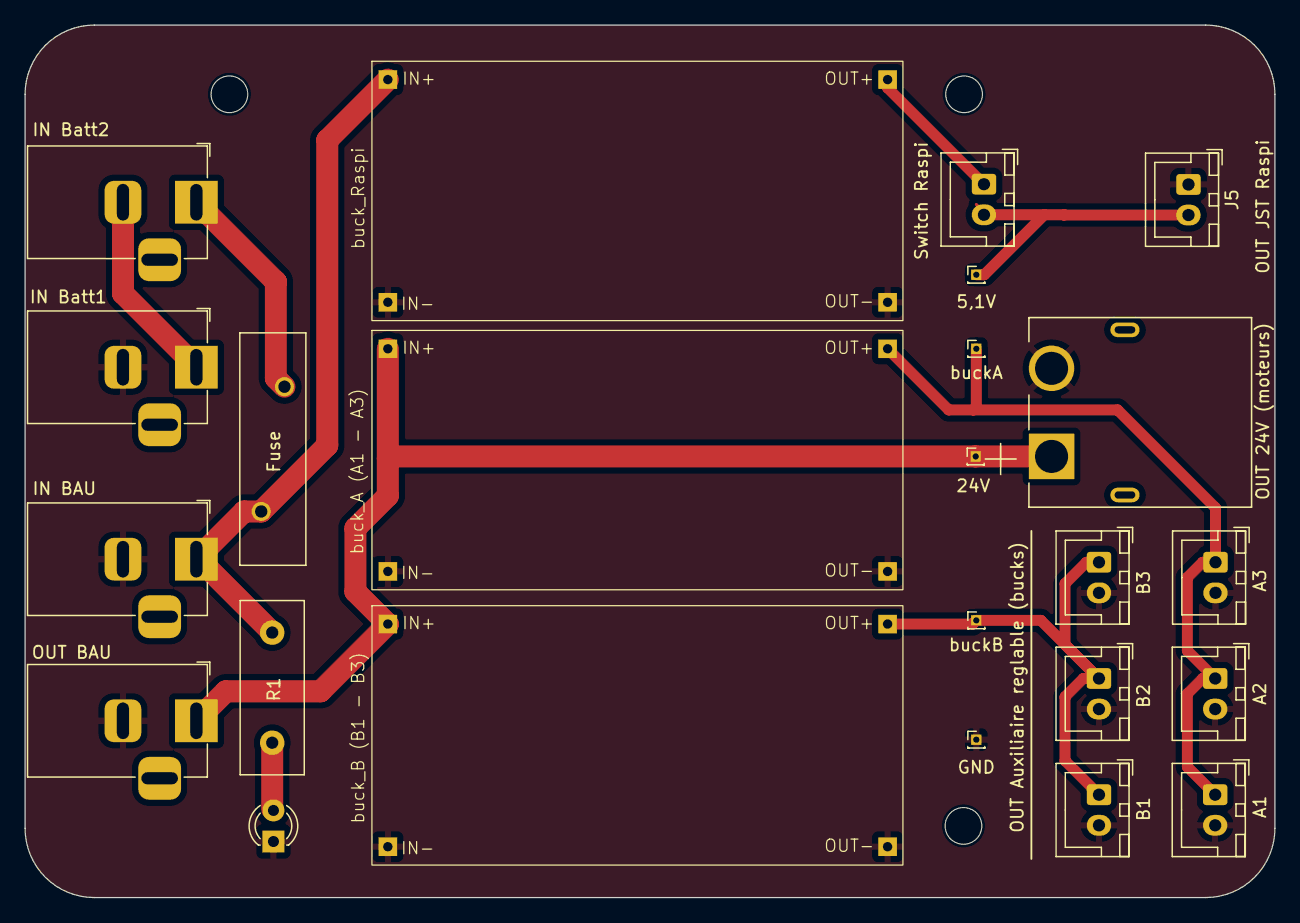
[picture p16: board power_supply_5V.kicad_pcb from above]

Board: 2 copper layers, 102.2 x 71.3 mm, 27 parts (0 on the bottom side), 10 nets.

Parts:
5,1V, 24V: Conn_01x01; PinHeader_1x01_P1.00mm_Vertical
D1: LED; LED_D3.0mm
F1: Fuse; Fuse_BelFuse_0ZRE0100FF_L18.7mm_W5.1mm
GND: Conn_01x01; PinHeader_1x01_P1.00mm_Vertical
H1, H2, H3: MountingHole; MountingHole_3mm
J1, J11: Conn_Jack; BarrelJack_Horizontal
J3, J4, J5, J12, J14, J16, J17, J18: Conn_JST_XH_2_pins; JST_XH_B2B-XH-A_1x02_P2.50mm_Vertical
J6: Conn_01x02_Pin; AMASS_XT60PW-M
J8, J13: Conn_01x02_Pin; BarrelJack_Horizontal
R1: R; R_Box_L14.0mm_W5.0mm_P9.00mm
U1, U2, U3: HW_411
buckA: Conn_01x01; PinHeader_1x01_P1.00mm_Vertical
buckB: Conn_01x01; PinHeader_1x01_P1.00mm_Vertical

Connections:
GND: D1.1 (K), GND.1, J3.2, J5.1, J6.2, J8.2, J11.2, J12.2, J13.2, J14.2, J16.2, J17.2, J18.2, U1.2 (IN-), U1.4 (OUT-), U2.2 (IN-), U2.4 (OUT-), U3.2 (IN-), U3.4 (OUT-)
unnamed: D1.2 (A), R1.2
unnamed: F1.1, J1.1
unnamed: J1.2, J11.1
unnamed: J4.1, U1.3 (OUT+)
unnamed: F1.2, J8.1, R1.1, U1.1 (IN+)
unnamed: J3.1, J12.1, J14.1, U2.3 (OUT+), buckB.1
unnamed: 24V.1, J6.1, J13.1, U2.1 (IN+), U3.1 (IN+)
unnamed: J16.1, J17.1, J18.1, U3.3 (OUT+), buckA.1
unnamed: 5,1V.1, J4.2, J5.2

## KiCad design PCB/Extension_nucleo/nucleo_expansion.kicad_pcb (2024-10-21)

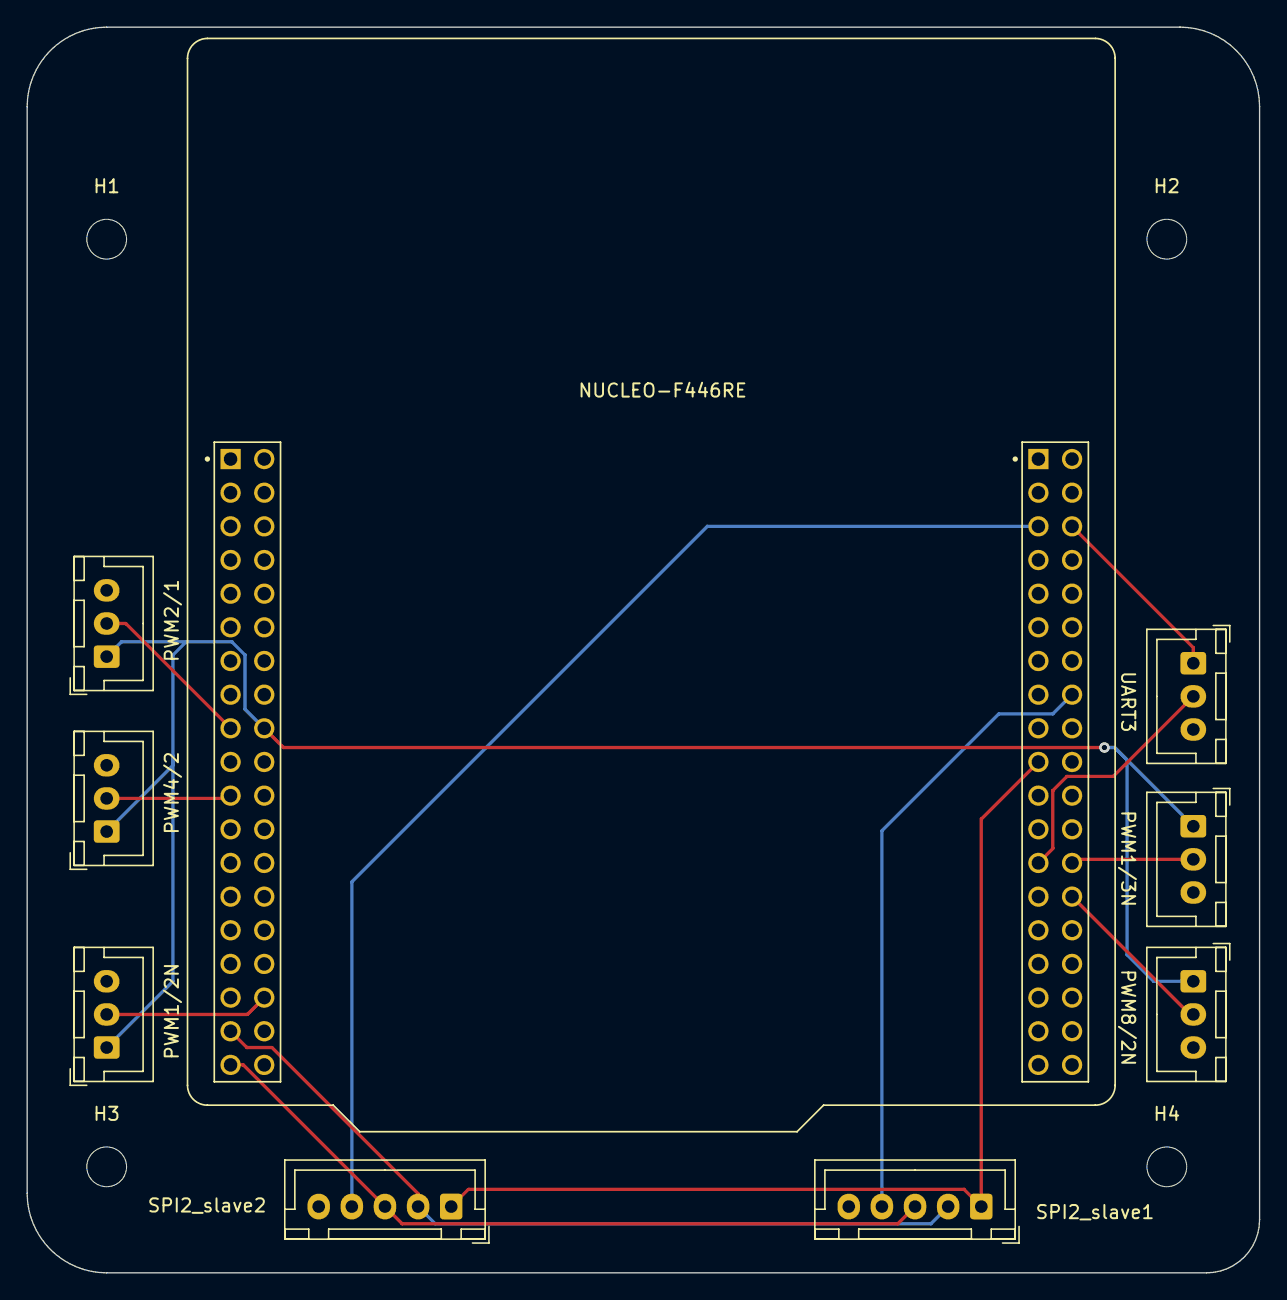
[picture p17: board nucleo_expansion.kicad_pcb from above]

Board: 2 copper layers, 93.0 x 94.0 mm, 13 parts (0 on the bottom side), 14 nets.

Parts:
H1, H2, H3, H4: MountingHole; MountingHole_3mm
J1: SPI2_slave1; JST_XH_B5B-XH-A_1x05_P2.50mm_Vertical
J2: SPI2_slave2; JST_XH_B5B-XH-A_1x05_P2.50mm_Vertical
J3: UART3; JST_XH_B3B-XH-A_1x03_P2.50mm_Vertical
J4: PWM2/1; JST_XH_B3B-XH-A_1x03_P2.50mm_Vertical
J5: PWM4/2; JST_XH_B3B-XH-A_1x03_P2.50mm_Vertical
J6: PWM1/2N; JST_XH_B3B-XH-A_1x03_P2.50mm_Vertical
J7: PWM1/3N; JST_XH_B3B-XH-A_1x03_P2.50mm_Vertical
J8: PWM8/2N; JST_XH_B3B-XH-A_1x03_P2.50mm_Vertical
U1: NUCLEO-F446RE; MODULE_NUCLEO-F446RE

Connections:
+5V: J4.1, J5.1, J6.1, J7.1, J8.1, U1.CN7_18 (CN7_+5V)
GND: J1.5, J2.5, J3.3, J4.3, J5.3, J6.3, J7.3, J8.3, U1.CN7_8 (CN7_GND), U1.CN7_19 (CN7_GND), U1.CN7_20 (CN7_GND), U1.CN7_22 (CN7_GND), U1.CN10_9 (CN10_GND), U1.CN10_20 (CN10_GND), U1.CN10_32 (AGND)
PWM1/2N: J6.2, U1.CN7_34 (PB0)
PWM1/3N: J7.2, U1.CN10_26 (PB15)
PWM2/1: J4.2, U1.CN7_17 (PA15)
PWM4/2: J5.2, U1.CN7_21 (PB7)
PWM8/2N: J8.2, U1.CN10_28 (PB14)
SPI2_CS1: J1.4, U1.CN10_16 (PB12)
SPI2_CS2: J2.4, U1.CN10_5 (PB9)
SPI2_MISO: J1.2, J2.2, U1.CN7_35 (PC2)
SPI2_MOSI: J1.3, J2.3, U1.CN7_37 (PC3)
SPI2_SCK: J1.1, J2.1, U1.CN10_19 (PC7)
UART3_RX: J3.1, U1.CN10_6 (PC5)
UART3_TX: J3.2, U1.CN10_25 (PB10)

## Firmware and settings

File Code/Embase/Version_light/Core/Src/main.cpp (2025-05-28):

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
/* Includes ------------------------------------------------------------------*/
#include "main.h"

/* USER CODE BEGIN Includes */
#include <stdlib.h>
#include "BlocMoteurs.hpp"
#include <math.h>

/* USER CODE END Includes */

/* USER CODE BEGIN PD */
#define STEPPER_STEP_MODE STEP_MODE_1_32
#define MAXACC 10.0
#define RAYON_ROUES 0.029 //m
#define RAYON_EMBASE 0.14 //m
/* USER CODE END PD */

SPI_HandleTypeDef hspi1;
SPI_HandleTypeDef hspi2;

TIM_HandleTypeDef htim1;
TIM_HandleTypeDef htim2;
TIM_HandleTypeDef htim4;
TIM_HandleTypeDef htim6;
TIM_HandleTypeDef htim8;

UART_HandleTypeDef huart2;
UART_HandleTypeDef huart3;
/* USER CODE BEGIN PV */
BlocMoteurs *moteurs;

volatile int32_t* mesures;
volatile double deplacement[] = {0, 0, 0}; //deplacement du robot par rapport au dernier appel de position
volatile double position[] = {0, 0, 0}; // position du robot par rapport au point de depart
volatile bool transmit_pos = false;
volatile bool motors_busy;

double distance_per_elementary_step = (DEG_PER_FULL_STEP*M_PI/180)/std::pow((float)2, (float)(STEPPER_STEP_MODE)) * RAYON_ROUES; //rayon roues: 29mm

uint8_t uart_received_char;

double dm1, dm2, dm3;

/* USER CODE END PV */

void SystemClock_Config(void);
static void MX_GPIO_Init(void);
static void MX_USART2_UART_Init(void);
static void MX_TIM2_Init(void);
static void MX_SPI1_Init(void);
static void MX_SPI2_Init(void);
static void MX_TIM1_Init(void);
static void MX_TIM4_Init(void);
static void MX_TIM8_Init(void);
static void MX_USART3_UART_Init(void);
static void MX_TIM6_Init(void);


/* USER CODE BEGIN PFP */
void moveSpeed(double vx, double vy, double wz);
void stop();

/* USER CODE END PFP */

/**
 * @brief  The application entry point.
 * @retval int
 */
int main(void) {
	/* MCU Configuration--------------------------------------------------------*/

	/* Reset of all peripherals, Initializes the Flash interface and the Systick. */
	HAL_Init();

	/* Configure the system clock */
	SystemClock_Config();

	/* Initialize all configured peripherals */
	MX_GPIO_Init();
	MX_USART2_UART_Init();
	MX_TIM2_Init();
	MX_SPI1_Init();
	MX_SPI2_Init();
	MX_TIM1_Init();
	MX_TIM4_Init();
	MX_TIM8_Init();
	MX_USART3_UART_Init();
	MX_TIM6_Init();
	/* USER CODE BEGIN 2 */

	//Start Timer2 interrupt (every 20 ms here)
	HAL_TIM_Base_Start_IT(&htim2);

	HAL_UART_Receive_IT(&huart2, &uart_received_char, sizeof(uint8_t));

	//Init motor class


	moteurs = new BlocMoteurs(&hspi1, reset_shield_1_GPIO_Port,
			reset_shield_1_Pin, ssel1_GPIO_Port, ssel1_Pin,
			reset_shield_2_GPIO_Port, reset_shield_2_Pin, ssel2_GPIO_Port,
			ssel2_Pin);

	moteurs->set_microstepping_mode(step_mode_t::STEPPER_STEP_MODE);
	moteurs->set_max_acc_moteurs(MAXACC, MAXACC, MAXACC, MAXACC);
	moteurs->set_max_dec_moteurs(MAXACC, MAXACC, MAXACC, MAXACC);


	// test steps

	// appel mesure pas ecoule
//	mesures = moteurs->mesure_pas_ecoule();
//
	uint32_t ** status_tab = moteurs->motors_get_status_and_clear_fault();

	moteurs->motors_on();
	moteurs->commande_step(6400*1.5, 0, 0, 6400*1.5); // 3, 0, 2, 1


//
//	HAL_Delay(5000);
//
//	mesures = moteurs->mesure_pas_ecoule();

//	while(1);

	/* USER CODE END 2 */

	/* Infinite loop */
	/* USER CODE BEGIN WHILE */
	while (1) {
		if(transmit_pos) {
			transmit_pos = false;

			//calcul du deplacement
			mesures = moteurs->mesure_pas_ecoule();
			dm1 = (double)(mesures[3]*distance_per_elementary_step);
			dm2 = (double)(mesures[2]*distance_per_elementary_step);
			dm3 = (double)(mesures[0]*distance_per_elementary_step);

			//deplacement dans le referentiel robot
			deplacement[0] = sqrt(3)/3 * (dm3 + dm1);//cos(M_PI/6) * (dm3 + dm1); //cos(M_PI/6) * (dm3 + dm1);			//dx
			deplacement[1] = 2.0/3.0 * dm2 + 1.0/3.0 * (- dm3 + dm1);                            // sin(M_PI/6) * (dm3 - dm1) - dm2;//sin(M_PI/6) * (dm3 - dm1) - dm2;	//dy
			deplacement[2] = ((dm3-dm1+dm2)/3.0) / (RAYON_EMBASE) ; // atan( ((dm3-dm1+dm2)/3) / (RAYON_EMBASE) );//(dm3-dm1+dm2)/3 / RAYON_EMBASE;				//dtheta

			//calcul de la position dans le referentiel table
			position[2] += deplacement[2]; //angle
			position[0] += (deplacement[0]*cos(position[2]) + deplacement[1]*sin(position[2])); //px  + deplacement[2]/2.0
			position[1] += (deplacement[1]*cos(position[2]) - deplacement[0]*sin(position[2])); //py


			char message[100] = "";

			sprintf(message, "%.4f %.4f %.4f\n", position[0], position[1], position[2]); // message pos
			//sprintf(message, "%f %f %f\n", deplacement[0], deplacement[1], deplacement[2]); // message depl
			//sprintf(message, "%ld %ld %ld\n", mesures[3], mesures[2], mesures[0]); //message raw values
			HAL_UART_Transmit(&huart2, (uint8_t*)message, sizeof(message), HAL_MAX_DELAY);
		}

		/* USER CODE END WHILE */

		/* USER CODE BEGIN 3 */
	}

	/* USER CODE END 3 */
}

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
/* USER CODE BEGIN 4 */


void moveSpeed(double vx, double vy, double wz)
{
	//calcul des vitesses
	double Wm1 = -1/(2*RAYON_ROUES) * vy - sqrt(3)/(2*RAYON_ROUES) * vx + RAYON_EMBASE / RAYON_ROUES * wz;
	double Wm3 = sqrt(3)/(2*RAYON_ROUES) * vx - 1/(2*RAYON_ROUES) * vy + RAYON_EMBASE / RAYON_ROUES * wz;
	double Wm2 = (1/RAYON_ROUES * vy + RAYON_EMBASE/RAYON_ROUES*wz);//1/RAYON_ROUES * vy + RAYON_EMBASE * wz;

	//pilotage des moteurs
	moteurs->motors_on();
	moteurs->commande_vitesses_absolues(Wm3, 0, Wm2, -Wm1);
}


void stop()
{
	moteurs->motors_stop_hard();
}


// GPIO interrupt
void HAL_GPIO_EXTI_Callback(uint16_t GPIO_Pin) {
	if (GPIO_Pin == GPIO_PIN_0) {
		// Motors are busy when pin low. Rising edge -> no longer busy
		motors_busy = false;
	}
}

//Redirect Uart callback to msg_handler if huart is huart2 peripheral
void HAL_UART_RxCpltCallback(UART_HandleTypeDef *huart) {
	if(huart->Instance == USART2)
	{
		switch(uart_received_char)
		{
		case '5':
			if(motors_busy) transmit_pos = true;
			stop();
			break;

		case '8':
			moveSpeed(0.1, 0, 0);
			break;

		case '2':
			moveSpeed(-0.1, 0, 0);
			break;

		case '4':
			moveSpeed(0, 0.1, 0);
			break;

		case '6':
			moveSpeed(0, -0.1, 0);
			break;

		case '7':
			moveSpeed(0, 0, 1);
			break;

		case '9':
			moveSpeed(0, 0, -1);
			break;

		case '0':
			transmit_pos = true; //trigger le calcul de la position et son envoi par uart
			break;

		case '.':
			position[0] = 0;
			position[1] = 0;
			position[2] = 0;
			break;



		default:
			break;
		}

		// ALWAYS READ UART
		HAL_UART_Receive_IT(&huart2, &uart_received_char, sizeof(uint8_t));
	}
}

//timers callbacks
void HAL_TIM_PeriodElapsedCallback(TIM_HandleTypeDef *htim) {
	if(htim == &htim2) {
		transmit_pos = true;
	}
}

/* USER CODE END 4 */
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


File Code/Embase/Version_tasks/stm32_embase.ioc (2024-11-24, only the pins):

Mcu.UserName=STM32F446RETx
PA10.GPIO_Label=ssel2
PA10.Signal=GPIO_Output
PA13.GPIO_Label=TMS
PA13.Signal=SYS_JTMS-SWDIO
PA14.GPIO_Label=TCK
PA14.Signal=SYS_JTCK-SWCLK
PA15.Signal=S_TIM2_CH1_ETR
PA2.GPIO_Label=USART_TX
PA2.Signal=USART2_TX
PA3.GPIO_Label=USART_RX
PA3.Signal=USART2_RX
PA4.GPIO_Label=ssel1
PA4.Signal=GPIO_Output
PA5.GPIO_Label=LD2 [Green Led]
PA5.Signal=GPIO_Output
PA6.Signal=SPI1_MISO
PA7.Signal=SPI1_MOSI
PB0.Signal=TIM1_CH2N
PB10.Signal=USART3_TX
PB12.Signal=GPIO_Output
PB14.Signal=TIM8_CH2N
PB15.Signal=TIM1_CH3N
PB3.Signal=SPI1_SCK
PB4.GPIO_Label=reset_shield_2
PB4.Signal=GPIO_Output
PB5.GPIO_Label=reset_shield_1
PB5.Signal=GPIO_Output
PB7.Signal=S_TIM4_CH2
PB9.Signal=GPIO_Output
PC0.Signal=GPXTI0
PC13.GPIO_Label=B1 [Blue PushButton]
PC13.Signal=GPXTI13
PC14-OSC32_IN.Signal=RCC_OSC32_IN
PC15-OSC32_OUT.Signal=RCC_OSC32_OUT
PC2.Signal=SPI2_MISO
PC3.Signal=SPI2_MOSI
PC5.Signal=USART3_RX
PC7.Signal=SPI2_SCK
PH0-OSC_IN.Signal=RCC_OSC_IN
PH1-OSC_OUT.Signal=RCC_OSC_OUT

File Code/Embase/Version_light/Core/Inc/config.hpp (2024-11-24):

#pragma once

/* Consigne de vitesse max envoyée au shield moteurs (en pulse per second) */
#define MAX_VITESSE 600.0

#define DEG_PER_FULL_STEP 1.8

#define BASE_MOVEMENT_DIST_M 0.05

// Nombre max de tâches stockées (buffer circulaire)
#define MAX_TASK_COUNT 300

#define BASE_MOTOR_DELAY_MS 100

#define coeff_1x 1
#define coeff_1y 1
#define coeff_1z 1

#define coeff_2x 1
#define coeff_2y 1
#define coeff_2z 1

#define coeff_3x 1
#define coeff_3y 1
#define coeff_3z 1

//Caracteristiques géométriques
#define diametre_embase 0.13 //en m
#define Rayon_Roue 0.055 //en m
#define coeff_Y 0.866025404 //sqrt(3)/2

#define W_MAX 10 //en /rad/s

/*
	Utile ?
#define V_MAX 1.5 //en /m/s
#define Delay_Rotation 2000 //en ms
#define Delay_Translation 10000 //en ms
*/
#define Coeff_erreur_y 1
#define Coeff_erreur_x 1
#define Coeff_erreur_z 45/44

#define Vitesse_moy 0.283 //en m/s
#define Vitesse_Rotation_moy 45 //en °/s
#define Nombre_instructions 100 //Nombre d'instruction maximum avant overflow

//Equipes
#define JAUNE 1
#define BLEU 0
#define Coef_Neg 1.1

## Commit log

2024-10-21 Ajout : PCB, Modèles 3D, Documentation initiale
    [BAU.ipt, Ensemble1.iam, RKEF400--3DModel-STEP-418109.STEP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]
2024-11-17 Ajout: push initial pour le LIDAR
    Elouan MARRON (je push depuis la RasPi, il faut se mettre d'accord sur une adresse mail pour l'instant je laisse la mienne)
2024-11-20 feat: timestamp
    Ajout des timestamps dans la récupération des données, à voir si on veut un timestamp par données ou juste le premier suffit
2024-11-24 Ajout code embase ancien
    [Ensemble1.0001.iam, Ensemble1.iam, barre_horizontale_support_pinces.ipt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]
2024-11-24 Correction de nommage et de références dans le projet CubeIDE
    [stm32_embase.ioc]
2024-11-25 Ajout fichiers 3D base balises plateau
    [base_balises_plateau.ipt]
2024-11-25 nouvelle version code embase ultra simple sans file de taches (directement piloté par le port usb)
2024-12-16 update pour le calcul de position. Il reste a revoir le calcul du heading & Cie
2025-03-03 tentative correction translation laterale
    [main.cpp]
2025-03-03 Branche de recup pour revenir a une version fonctionnelle
2025-03-07 ajout code python de base pour controle de l'embase
2025-03-07 mouvement de demo
2025-03-11 update odometrie
2025-03-14 feat: described LIDAR procedure
    Dans l'idée, il faudrait suivre cette procédure, c'est la plus simple. Mais tout est ouvert à suggestions.
2025-03-18 ajout support banderole, impression en cours
    [support banderole.ipt]
2025-03-23 Ajout driver lidar et chaine de compilation + script python de test du driver

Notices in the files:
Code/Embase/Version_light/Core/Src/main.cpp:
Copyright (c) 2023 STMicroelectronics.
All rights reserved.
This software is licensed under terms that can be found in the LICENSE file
